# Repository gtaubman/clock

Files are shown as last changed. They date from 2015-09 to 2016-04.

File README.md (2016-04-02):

# Digital LED Clock

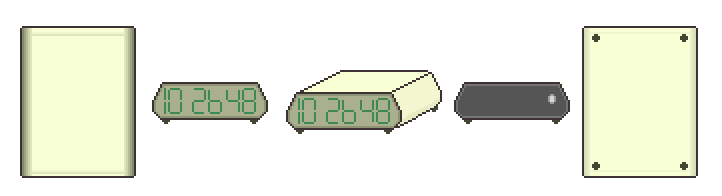
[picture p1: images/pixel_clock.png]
Pixel Clock


This project contains KiCad board schematics, PCB layouts, and firmware for my
digital clock.

The clock features buttons to set the time, a hold button to aid in syncing the
clock to another time source, and a switch to toggle the right-most display
between showing seconds and the current temperature as reported by the real-time
clock.

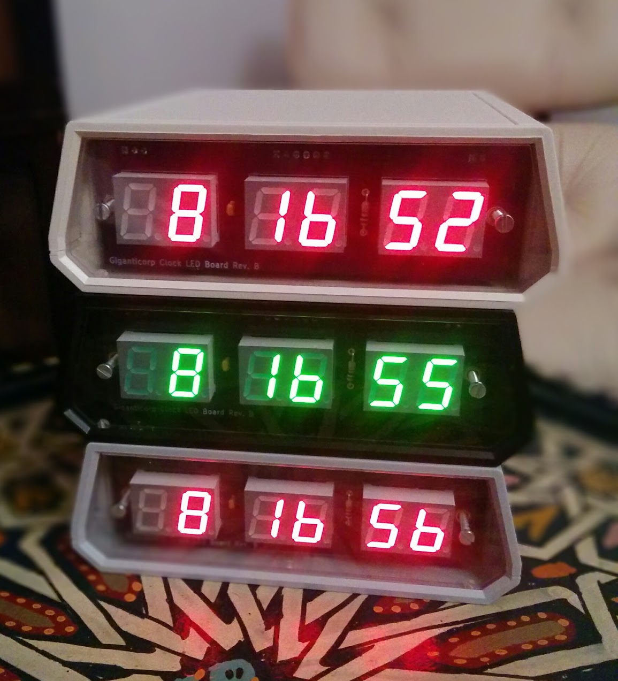
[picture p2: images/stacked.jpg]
Clock In Case

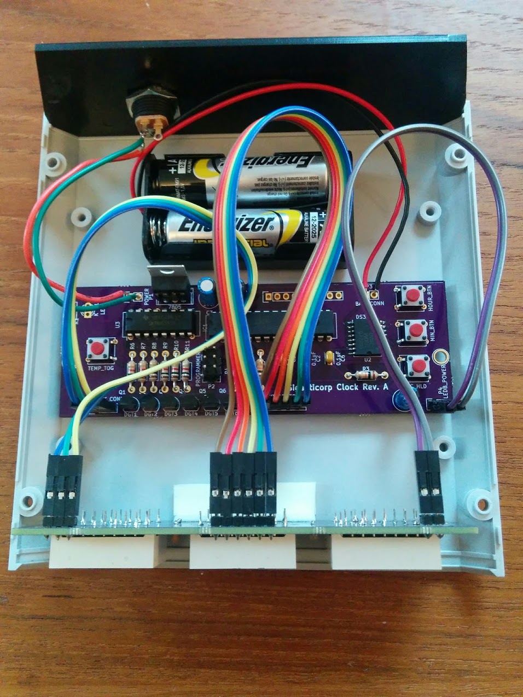
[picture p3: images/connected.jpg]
Clock Inside


The clock is divided into two PCBs:

## The LED Board

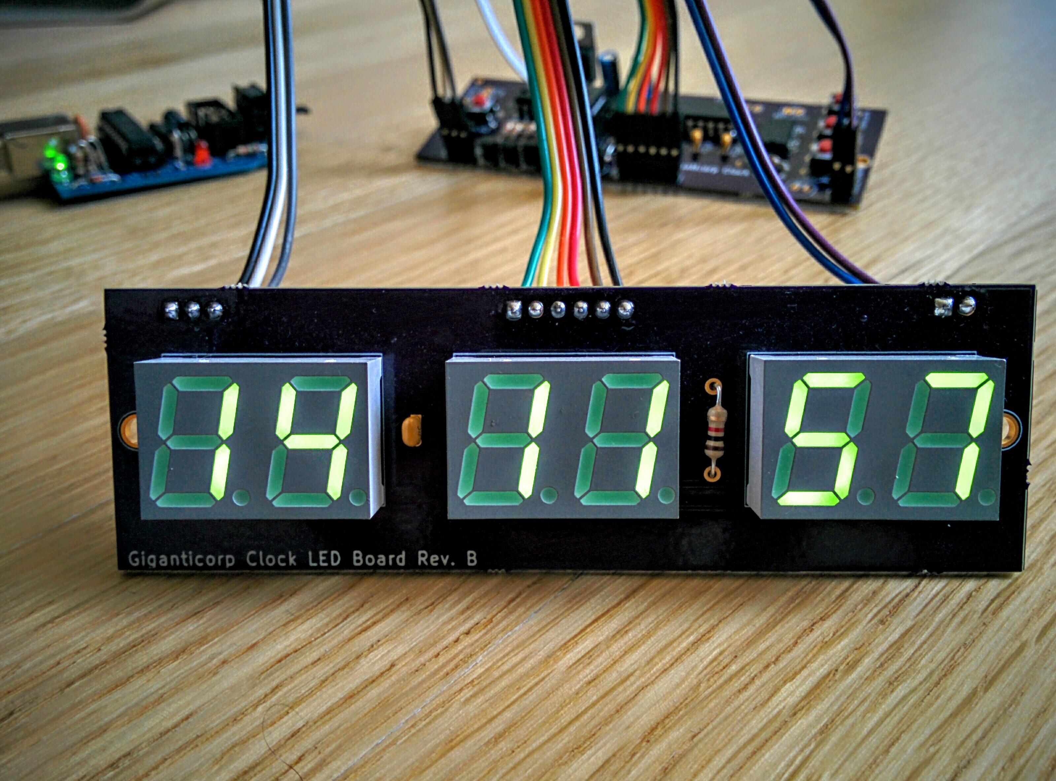
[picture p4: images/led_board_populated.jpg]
LED Board Populated


Schematic:

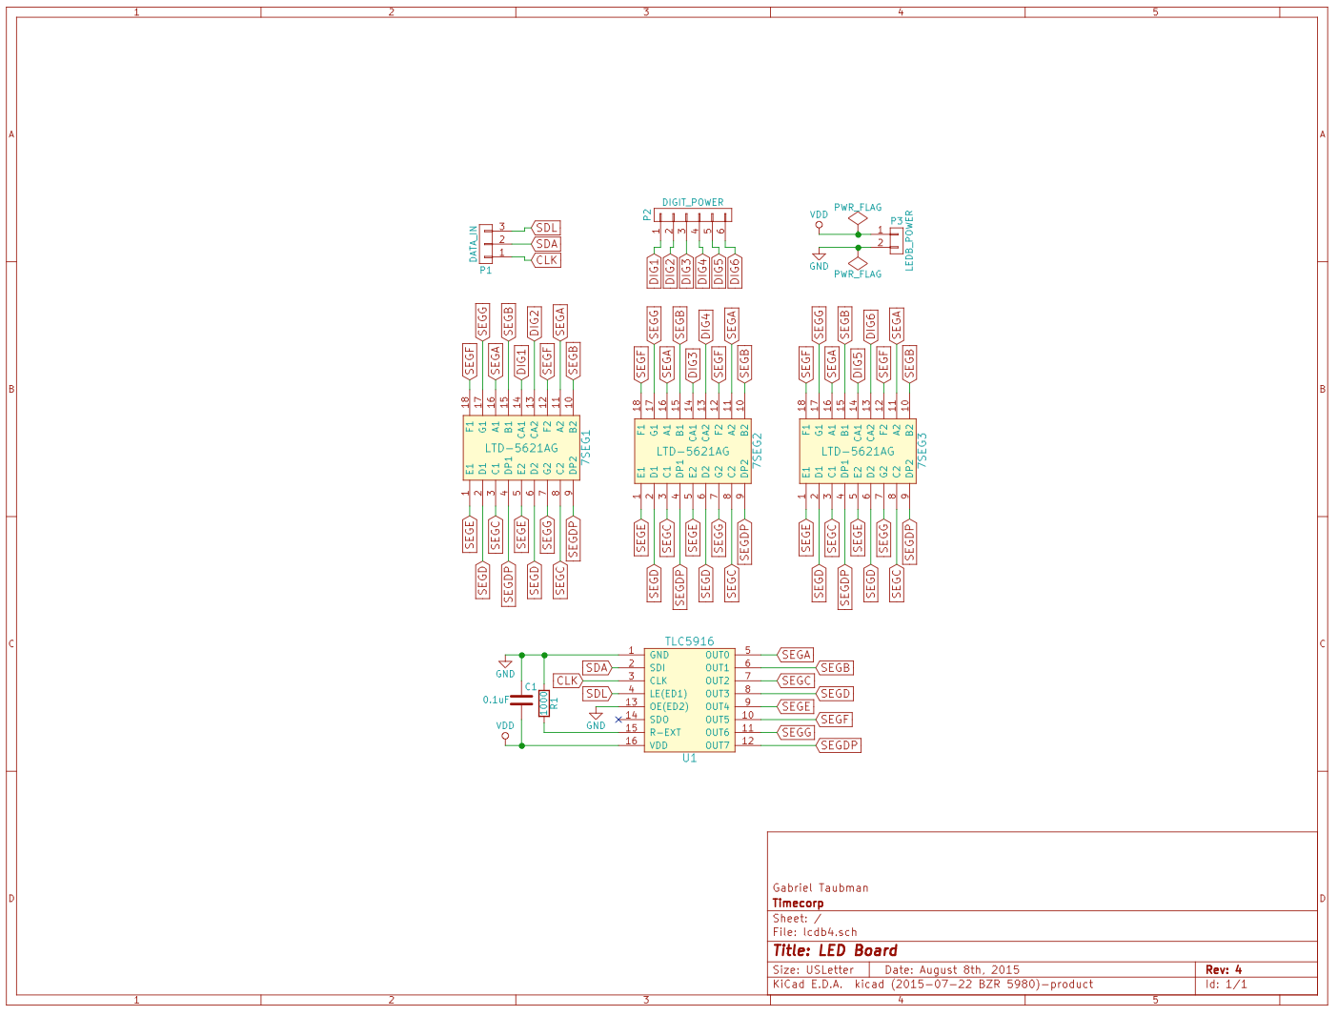
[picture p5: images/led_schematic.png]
LED Board Schematic


PCB Layout:

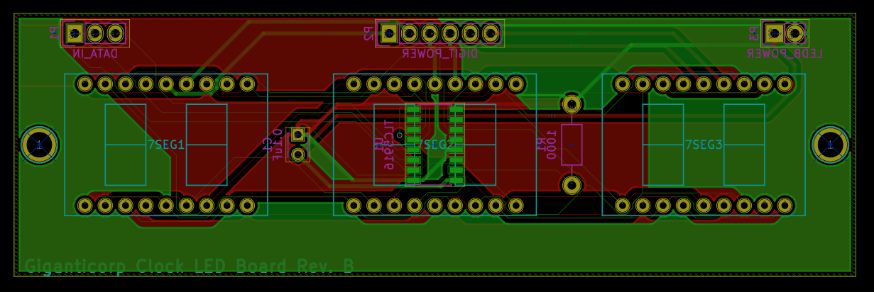
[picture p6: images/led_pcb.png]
LED Board PCB


PCB fabricated by OSH Park:

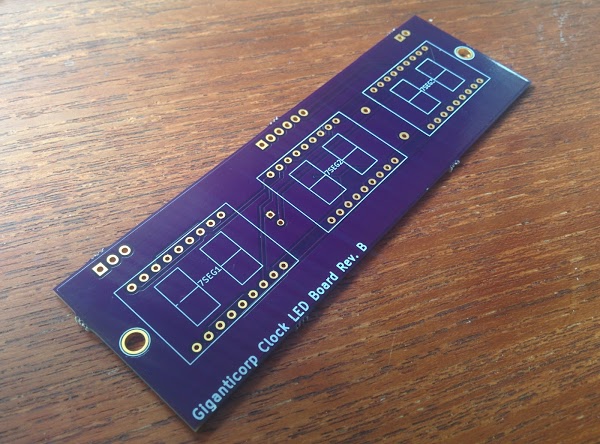
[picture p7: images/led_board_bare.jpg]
LED Board


This board contains:

1.  Three 2-digit 7-segment displays (Lite-On LTG-5612AG).
1.  A TLC5916 constant-current LED driver to drive the LEDs.
1.  A 0.1 uF decoupling capacitor for the TLC5916.
1.  A 1000 Ohm resistor to set the current allowed through the TLC5916.
1.  6 power pins to drive the individual digits.
1.  3 serial data pins to drive the TLC5916 (serial data, serial clock, latch).
1.  2 pins for power and ground for the TLC5916.

## The Clock Board

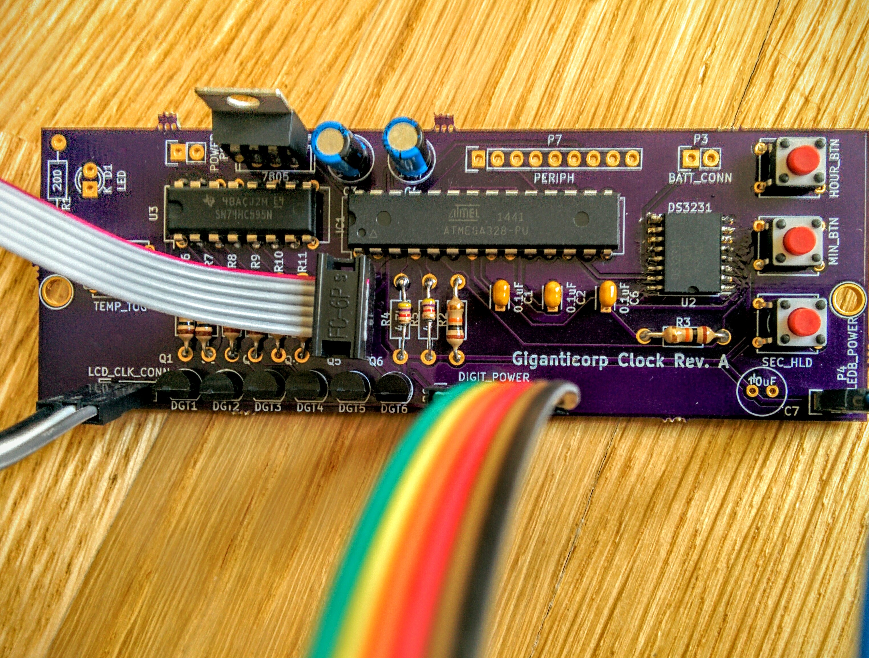
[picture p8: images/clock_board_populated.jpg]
Clock Board Populated


Schematic:

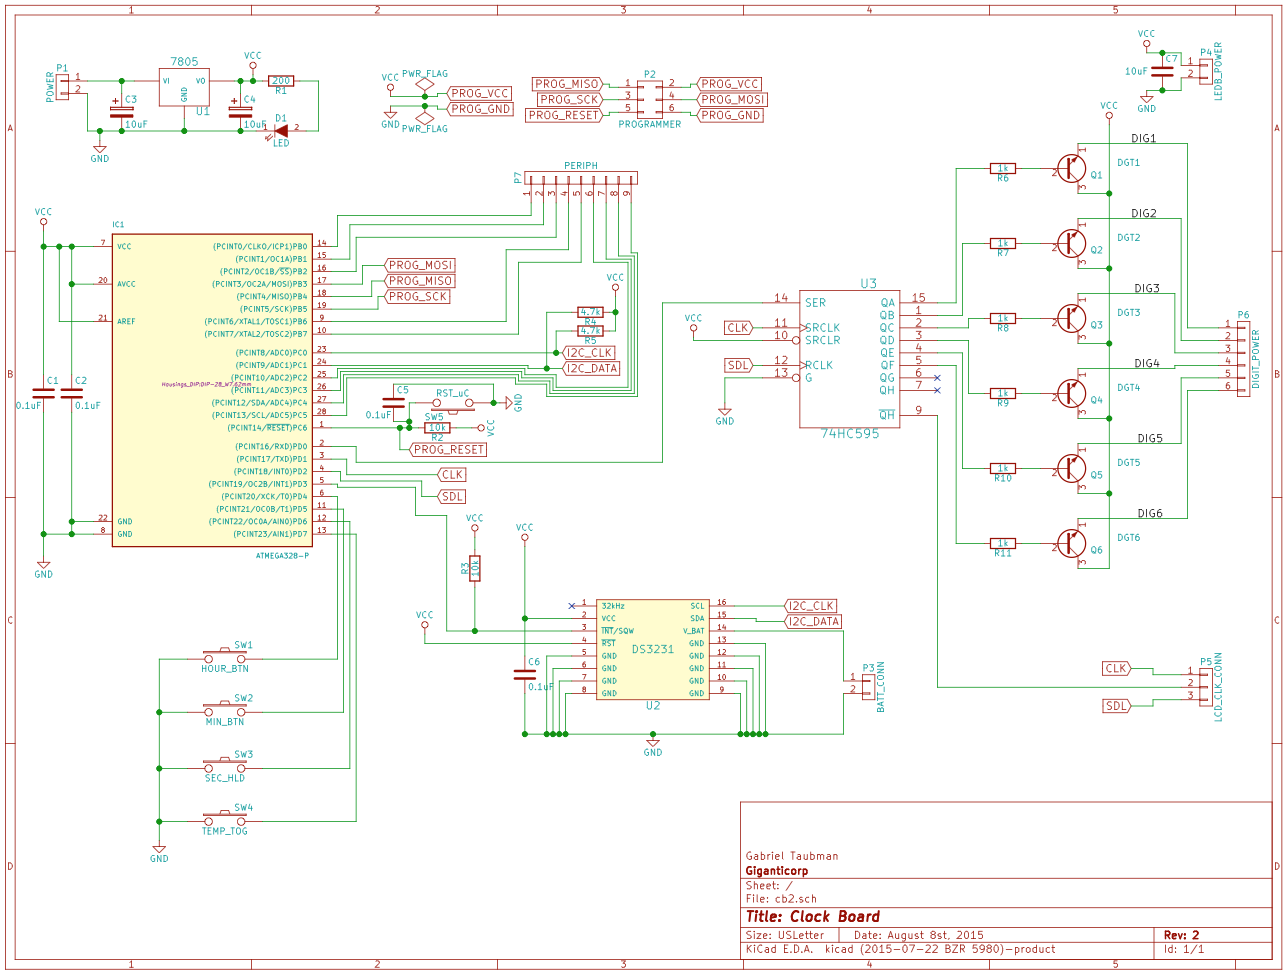
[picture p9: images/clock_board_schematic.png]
Clock Board Schematic


PCB Layout:

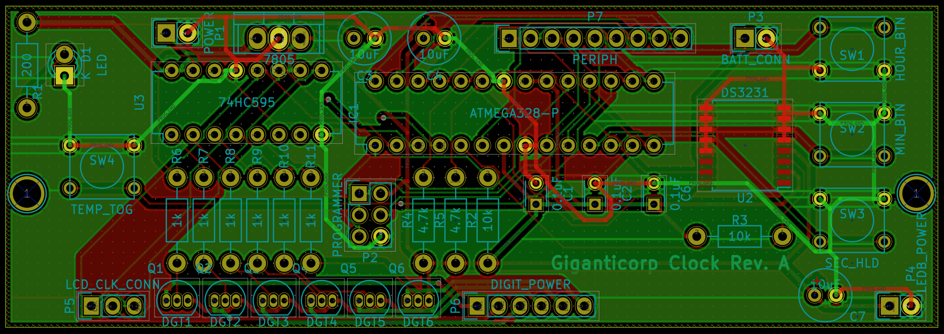
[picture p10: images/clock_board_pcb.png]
Clock Board PCB


PCB fabricated by OSH Park:

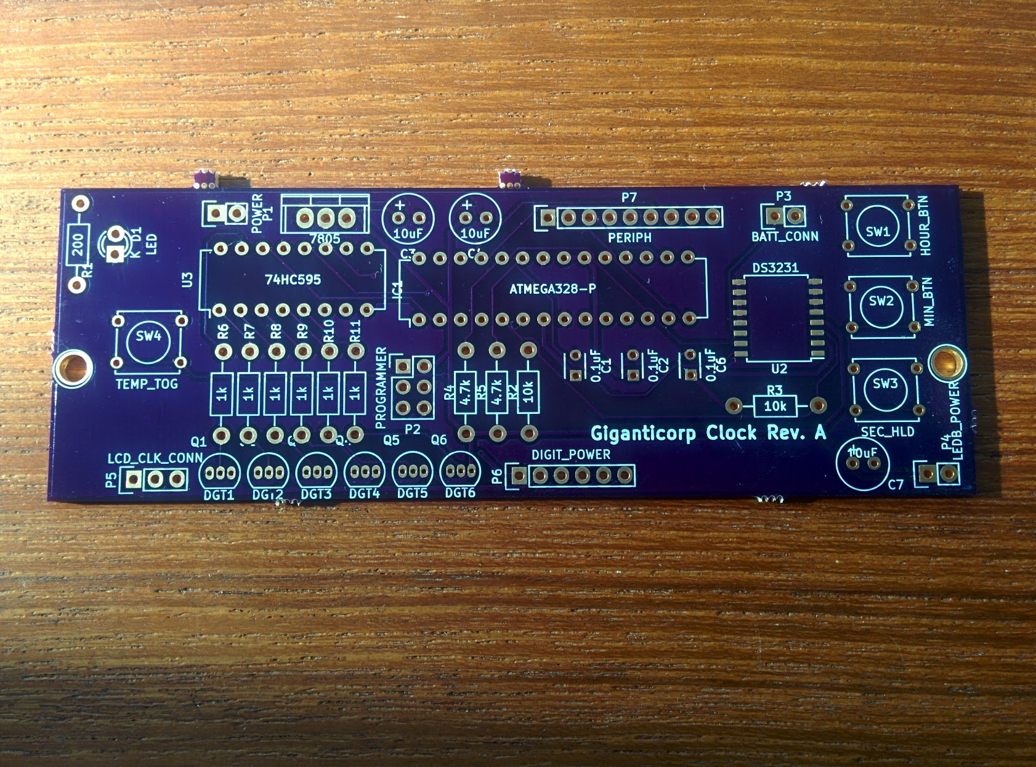
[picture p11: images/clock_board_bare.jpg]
Clock Board


The clock board is responsible for driving the entire clock logic, as well as
interfacing with the real-time clock chip, and allowing user control over the
clock functionality.  It consists of:

1.  One Atmega 328pu running the show.
1.  One DS3231 real-time clock, communicating with the AVR over i2c.
1.  One 74HC595 shift register to control which digit is powered on.
1.  6 transistors to power on digits.
1.  6 1k, 2 4.7k, and 2 10k resistors.
1.  4 push buttons for setting the time and temperature display modes.
1.  3 decoupling capacitors.
1.  2 10uF capacitors and a 7805 voltage regulator for supplying power.
1.  Pins to send power, data, and chip power to the LED board.
1.  An optional LED to indicate when the board is powered on.

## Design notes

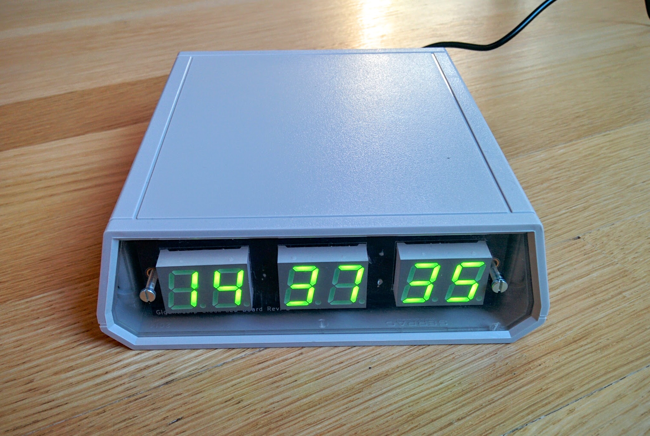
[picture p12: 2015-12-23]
images/clock_case.jpg

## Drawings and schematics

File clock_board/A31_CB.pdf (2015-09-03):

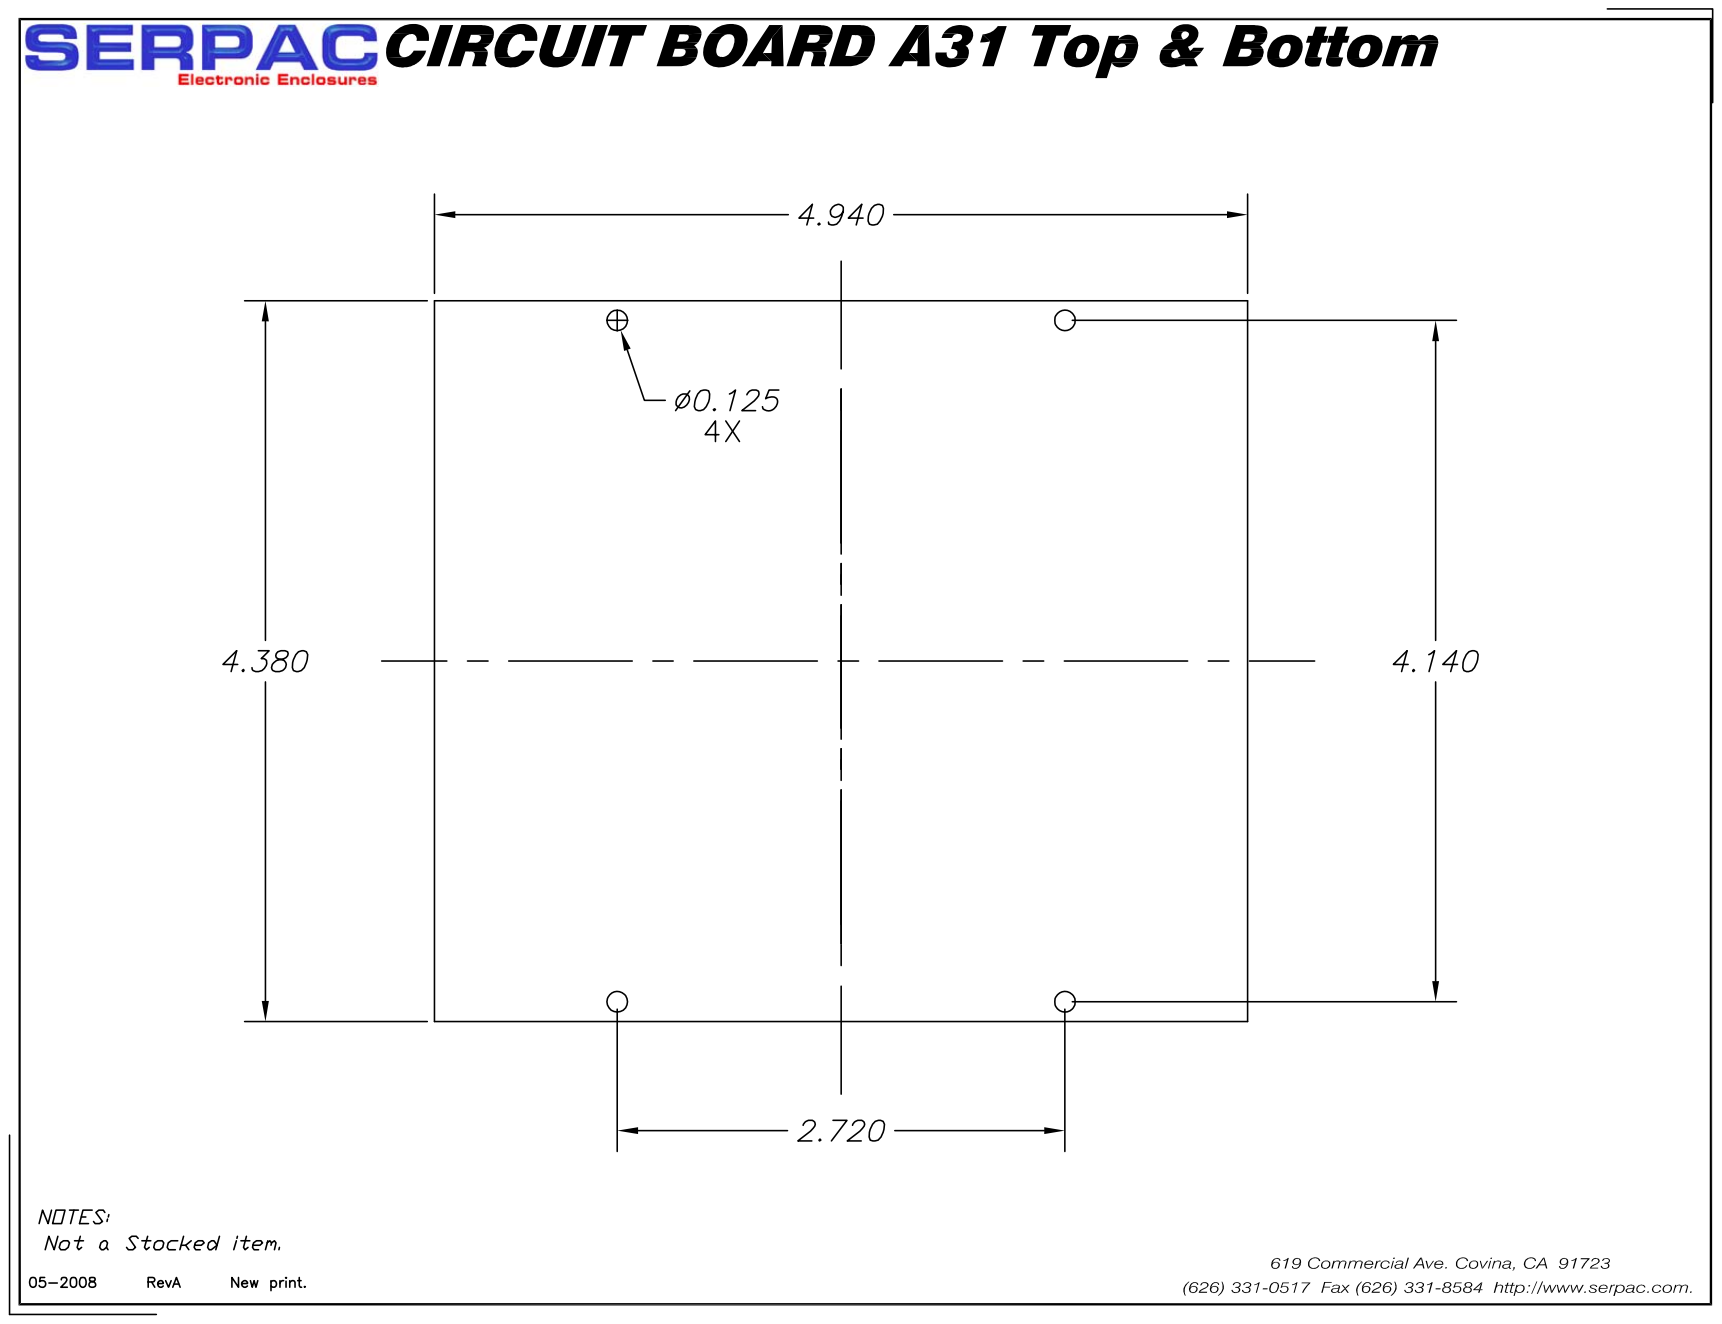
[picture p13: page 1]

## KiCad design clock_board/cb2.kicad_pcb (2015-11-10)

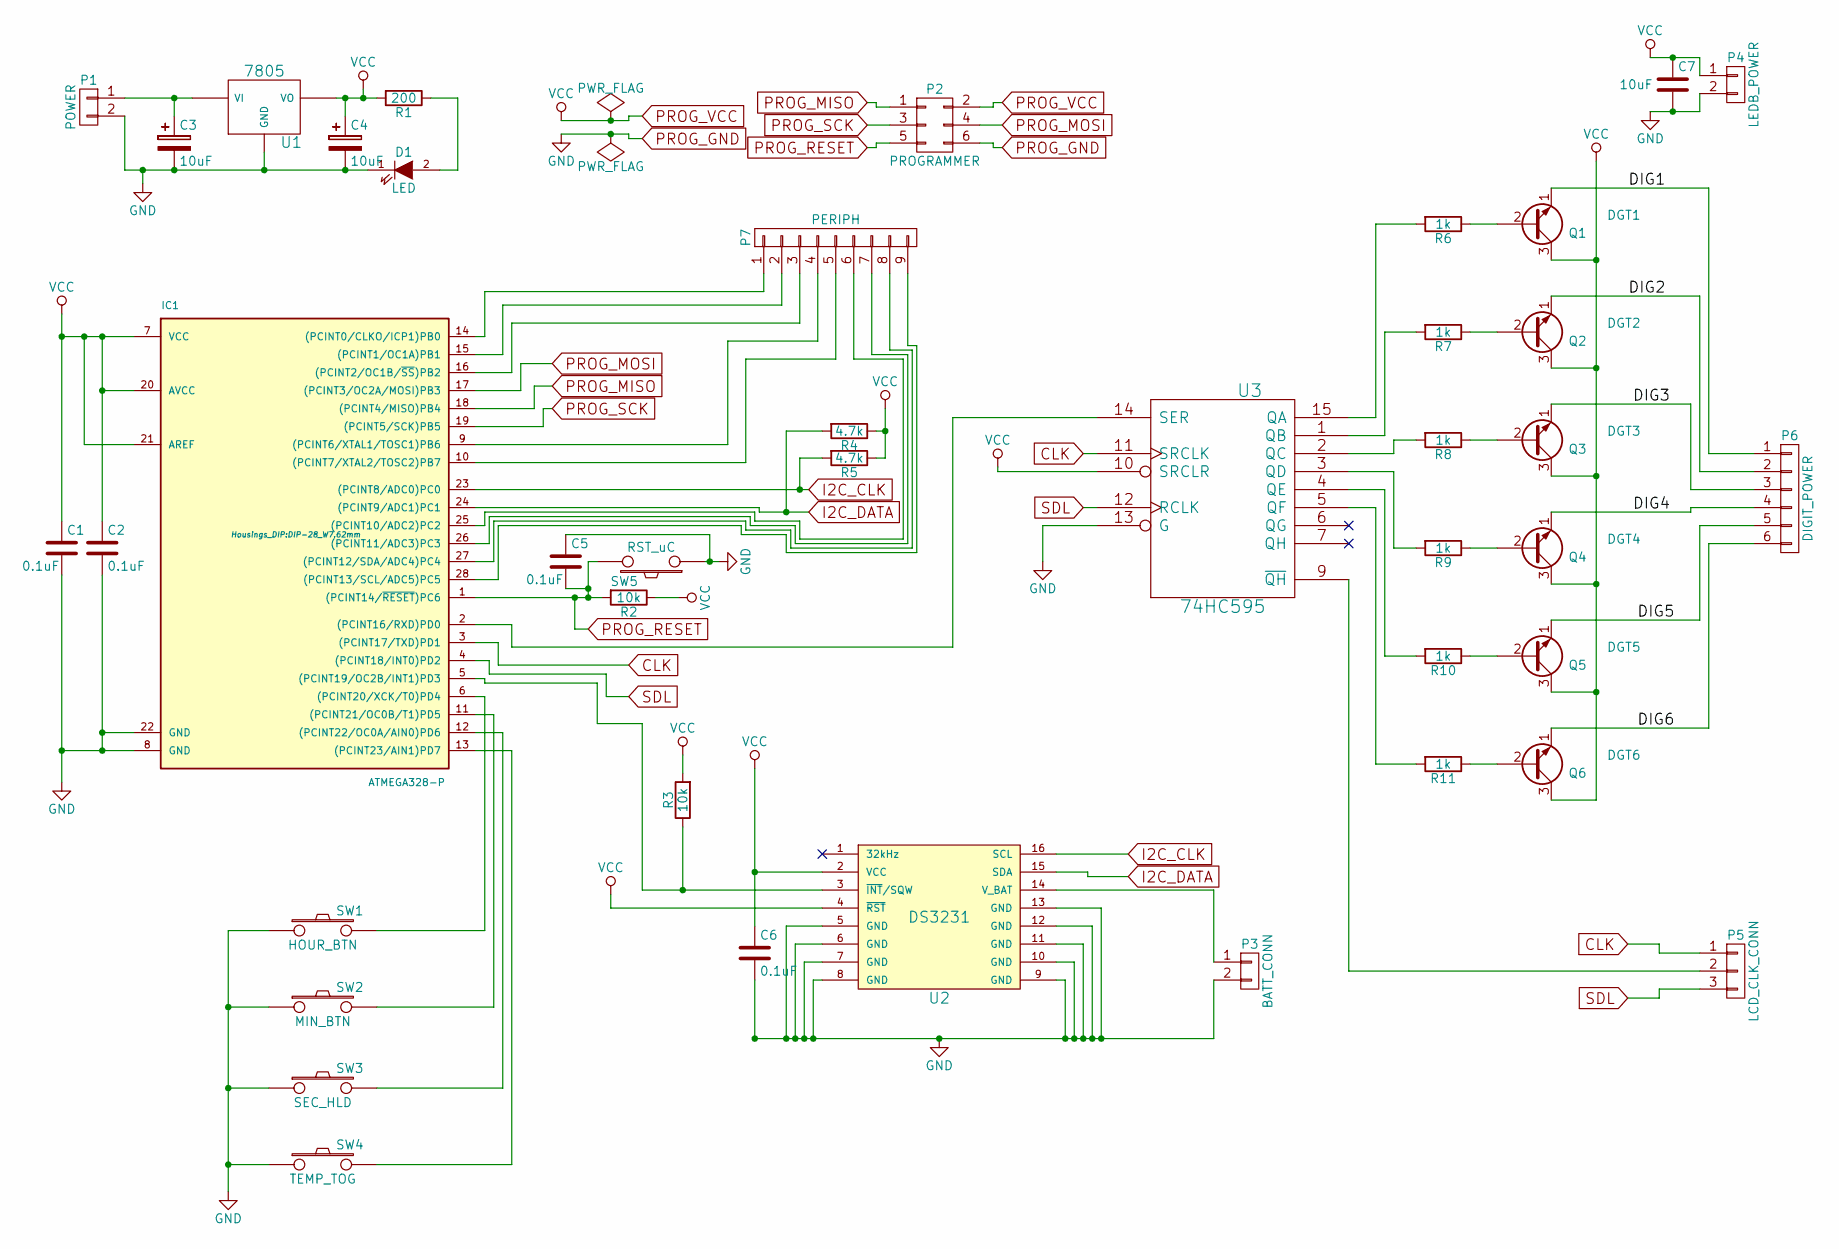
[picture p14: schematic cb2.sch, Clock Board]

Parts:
C1, C2, C5, C6: 0.1uF; C_Disc_D3_P2.5
C3, C4, C7: 10uF; Elko_vert_11.2x6.3mm_RM2.5
D1: LED; LED-3MM
IC1: ATMEGA328-P; DIP-28_W7.62mm
P1: POWER; Pin_Header_Straight_1x02
P2: PROGRAMMER; Pin_Header_Straight_2x03
P3: BATT_CONN; Pin_Header_Straight_1x02
P4: LEDB_POWER; Pin_Header_Straight_1x02
P5: LCD_CLK_CONN; Pin_Header_Straight_1x03
P6: DIGIT_POWER; Pin_Header_Straight_1x06
P7: PERIPH; Pin_Header_Straight_1x09
Q1: DGT1; TO-92_Inline_Narrow_Oval
Q2: DGT2; TO-92_Inline_Narrow_Oval
Q3: DGT3; TO-92_Inline_Narrow_Oval
Q4: DGT4; TO-92_Inline_Narrow_Oval
Q5: DGT5; TO-92_Inline_Narrow_Oval
Q6: DGT6; TO-92_Inline_Narrow_Oval
R1: 200; Resistor_Horizontal_RM10mm
R2, R3: 10k; Resistor_Horizontal_RM10mm
R4, R5: 4.7k; Resistor_Horizontal_RM10mm
R6, R7, R8, R9, R10, R11: 1k; Resistor_Horizontal_RM10mm
SW1: HOUR_BTN; SW_PUSH_SMALL
SW2: MIN_BTN; SW_PUSH_SMALL
SW3: SEC_HLD; SW_PUSH_SMALL
SW4: TEMP_TOG; SW_PUSH_SMALL
SW5: RST_uC; SW_PUSH_SMALL
U1: 7805; TO-220
U2: DS3231; SOIC-16_7.5x10.3mm_Pitch1.27mm
U3: 74HC595; DIP-16_W7.62mm

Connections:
/DIG1: P6.1, Q1.1 (E)
/DIG2: P6.2, Q2.1 (E)
/DIG3: P6.3, Q3.1 (E)
/DIG4: P6.4, Q4.1 (E)
/DIG5: P6.5, Q5.1 (E)
/DIG6: P6.6, Q6.1 (E)
CLK: IC1.3 ((PCINT17/TXD)PD1), P5.1, U3.11 (SRCLK)
I2C_CLK: IC1.23 ((PCINT8/ADC0)PC0), R5.2, U2.16 (SCL)
I2C_DATA: IC1.24 ((PCINT9/ADC1)PC1), R4.2, U2.15 (SDA)
unnamed: C3.1, P1.1, U1.1 (VI)
unnamed: D1.2 (A), R1.1
unnamed: IC1.2 ((PCINT16/RXD)PD0), U3.14 (SER)
unnamed: IC1.5 ((PCINT19/OC2B/INT1)PD3), R3.1, U2.3 (~INT~/SQW)
unnamed: IC1.6 ((PCINT20/XCK/T0)PD4), SW1.2
unnamed: IC1.9 ((PCINT6/XTAL1/TOSC1)PB6), P7.4
unnamed: IC1.10 ((PCINT7/XTAL2/TOSC2)PB7), P7.5
unnamed: IC1.11 ((PCINT21/OC0B/T1)PD5), SW2.2
unnamed: IC1.12 ((PCINT22/OC0A/AIN0)PD6), SW3.2
unnamed: IC1.13 ((PCINT23/AIN1)PD7), SW4.2
unnamed: IC1.14 ((PCINT0/CLKO/ICP1)PB0), P7.1
unnamed: IC1.15 ((PCINT1/OC1A)PB1), P7.2
unnamed: IC1.16 ((PCINT2/OC1B/~SS~)PB2), P7.3
unnamed: IC1.25 ((PCINT10/ADC2)PC2), P7.6
unnamed: IC1.26 ((PCINT11/ADC3)PC3), P7.7
unnamed: IC1.27 ((PCINT12/SDA/ADC4)PC4), P7.8
unnamed: IC1.28 ((PCINT13/SCL/ADC5)PC5), P7.9
unnamed: P3.1, U2.14 (V_BAT)
unnamed: P5.2, U3.9 (~QH)
unnamed: Q1.2 (B), R6.1
unnamed: Q2.2 (B), R7.1
unnamed: Q3.2 (B), R8.1
unnamed: Q4.2 (B), R9.1
unnamed: Q5.2 (B), R10.1
unnamed: Q6.2 (B), R11.1
unnamed: R6.2, U3.15 (QA)
unnamed: R7.2, U3.1 (QB)
unnamed: R8.2, U3.2 (QC)
unnamed: R9.2, U3.3 (QD)
unnamed: R10.2, U3.4 (QE)
unnamed: R11.2, U3.5 (QF)
PROG_GND: C1.2, C2.2, C3.2, C4.2, C5.1, C6.2, C7.2, D1.1 (K), IC1.8 (GND), IC1.22 (GND), P1.2, P2.6, P3.2, P4.2, SW1.1, SW2.1, SW3.1, SW4.1, SW5.1, U1.2 (GND), U2.5 (GND), U2.6 (GND), U2.7 (GND), U2.8 (GND), U2.9 (GND), U2.10 (GND), U2.11 (GND), U2.12 (GND), U2.13 (GND), U3.8 (GND), U3.13 (G)
PROG_MISO: IC1.18 ((PCINT4/MISO)PB4), P2.1
PROG_MOSI: IC1.17 ((PCINT3/OC2A/MOSI)PB3), P2.4
PROG_RESET: C5.2, IC1.1 ((PCINT14/~RESET~)PC6), P2.5, R2.2, SW5.2
PROG_SCK: IC1.19 ((PCINT5/SCK)PB5), P2.3
PROG_VCC: C1.1, C2.1, C4.1, C6.1, C7.1, IC1.7 (VCC), IC1.20 (AVCC), IC1.21 (AREF), P2.2, P4.1, Q1.3 (C), Q2.3 (C), Q3.3 (C), Q4.3 (C), Q5.3 (C), Q6.3 (C), R1.2, R2.1, R3.2, R4.1, R5.1, U1.3 (VO), U2.2 (VCC), U2.4 (~RST), U3.10 (SRCLR), U3.16 (VCC)
SDL: IC1.4 ((PCINT18/INT0)PD2), P5.3, U3.12 (RCLK)

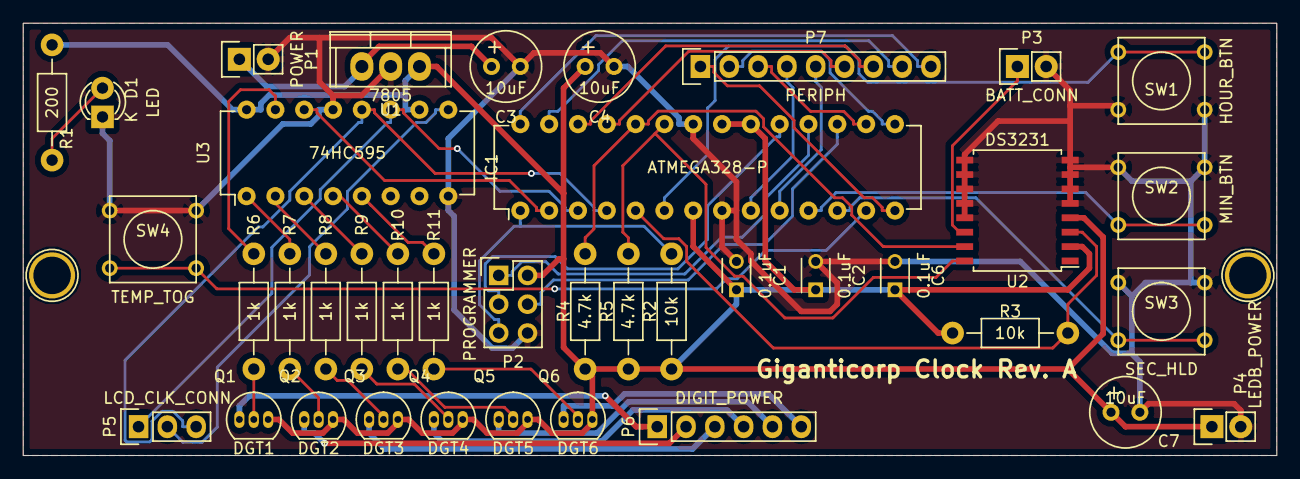
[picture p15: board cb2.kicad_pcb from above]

Board: 2 copper layers, 110.5 x 38.1 mm, 41 parts (0 on the bottom side), 47 nets.

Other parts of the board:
REF1, REF2: 1pin

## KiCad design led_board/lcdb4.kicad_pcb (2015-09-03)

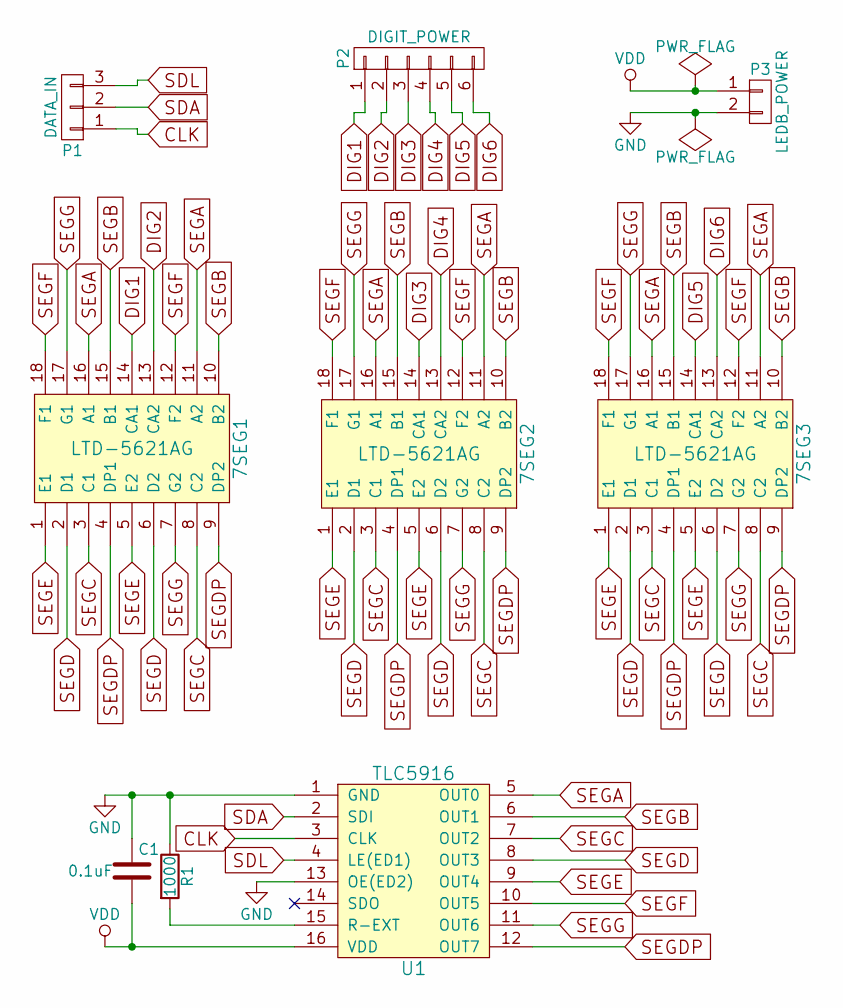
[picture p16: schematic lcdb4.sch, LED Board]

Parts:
7SEG1, 7SEG2, 7SEG3: LTD-5621AG
C1: 0.1uF; C_Disc_D3_P2.5
P1: DATA_IN; Pin_Header_Straight_1x03
P2: DIGIT_POWER; Pin_Header_Straight_1x06
P3: LEDB_POWER; Pin_Header_Straight_1x02
R1: 1000; Resistor_Horizontal_RM10mm
U1: TLC5916; SOIC-16_3.9x9.9mm_Pitch1.27mm

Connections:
CLK: P1.1, U1.3 (CLK)
DIG1: 7SEG1.14 (CA1), P2.1
DIG2: 7SEG1.13 (CA2), P2.2
DIG3: 7SEG2.14 (CA1), P2.3
DIG4: 7SEG2.13 (CA2), P2.4
DIG5: 7SEG3.14 (CA1), P2.5
DIG6: 7SEG3.13 (CA2), P2.6
GND: C1.1, P3.2, R1.1, U1.1 (GND), U1.13 (OE(ED2))
unnamed: R1.2, U1.15 (R-EXT)
SDA: P1.2, U1.2 (SDI)
SDL: P1.3, U1.4 (LE(ED1))
SEGA: 7SEG1.11 (A2), 7SEG1.16 (A1), 7SEG2.11 (A2), 7SEG2.16 (A1), 7SEG3.11 (A2), 7SEG3.16 (A1), U1.5 (OUT0)
SEGB: 7SEG1.10 (B2), 7SEG1.15 (B1), 7SEG2.10 (B2), 7SEG2.15 (B1), 7SEG3.10 (B2), 7SEG3.15 (B1), U1.6 (OUT1)
SEGC: 7SEG1.3 (C1), 7SEG1.8 (C2), 7SEG2.3 (C1), 7SEG2.8 (C2), 7SEG3.3 (C1), 7SEG3.8 (C2), U1.7 (OUT2)
SEGD: 7SEG1.2 (D1), 7SEG1.6 (D2), 7SEG2.2 (D1), 7SEG2.6 (D2), 7SEG3.2 (D1), 7SEG3.6 (D2), U1.8 (OUT3)
SEGDP: 7SEG1.4 (DP1), 7SEG1.9 (DP2), 7SEG2.4 (DP1), 7SEG2.9 (DP2), 7SEG3.4 (DP1), 7SEG3.9 (DP2), U1.12 (OUT7)
SEGE: 7SEG1.1 (E1), 7SEG1.5 (E2), 7SEG2.1 (E1), 7SEG2.5 (E2), 7SEG3.1 (E1), 7SEG3.5 (E2), U1.9 (OUT4)
SEGF: 7SEG1.12 (F2), 7SEG1.18 (F1), 7SEG2.12 (F2), 7SEG2.18 (F1), 7SEG3.12 (F2), 7SEG3.18 (F1), U1.10 (OUT5)
SEGG: 7SEG1.7 (G2), 7SEG1.17 (G1), 7SEG2.7 (G2), 7SEG2.17 (G1), 7SEG3.7 (G2), 7SEG3.17 (G1), U1.11 (OUT6)
VDD: C1.2, P3.1, U1.16 (VDD)

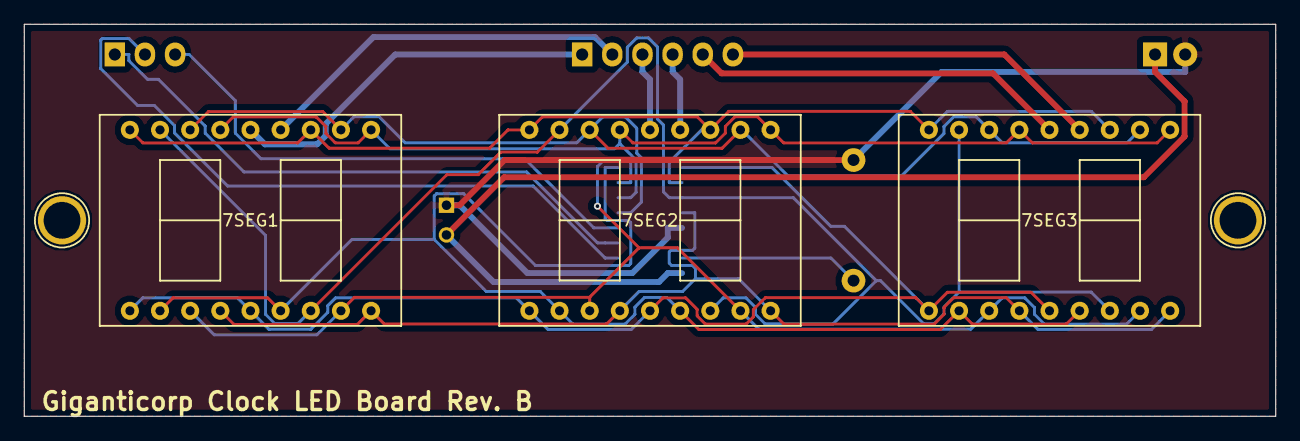
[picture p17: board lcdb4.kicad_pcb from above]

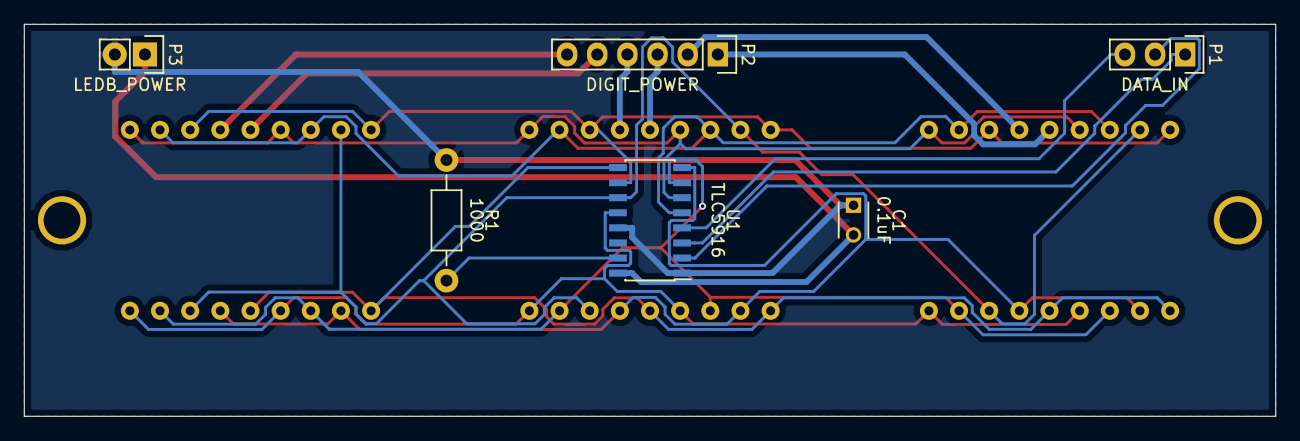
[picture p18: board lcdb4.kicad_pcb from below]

Board: 2 copper layers, 105.4 x 33.0 mm, 11 parts (6 on the bottom side), 20 nets.

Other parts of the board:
REF1, REF2: 1pin

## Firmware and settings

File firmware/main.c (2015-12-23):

/* Name: main.c
 * Author: <insert your name here>
 * Copyright: <insert your copyright message here>
 * License: <insert your license reference here>
 */

#include <avr/io.h>
#include <avr/interrupt.h>
#include <util/delay.h>
#include <util/twi.h>

#include "button.h"
#include "i2cmaster.h"
#include "rtc.h"

// Ports for serial clock, data, and latch.
#define SDA_PORT PORTD
#define CLK_PORT PORTD
#define SDL_PORT PORTD

// Pins for serial clock, data, and latch.
#define SDA_PIN 0
#define CLK_PIN 1
#define SDL_PIN 2

#define RTC_INTERRUPT_PIN 3

#define HOUR_BTN_PIN 4
#define MIN_BTN_PIN 5
#define SEC_BTN_PIN 6
#define TEMP_TOG_BTN_PIN 7

typedef struct digit {
  unsigned int a : 1;
  unsigned int b : 1;
  unsigned int c : 1;
  unsigned int d : 1;
  unsigned int e : 1;
  unsigned int f : 1;
  unsigned int g : 1;
  unsigned int dp : 1;
} Digit;

// Digit segment configuration for each digit.
Digit zero =  {1, 1, 1, 1, 1, 1, 0, 0};
Digit one =   {0, 1, 1, 0, 0, 0, 0, 0};
Digit two =   {1, 1, 0, 1, 1, 0, 1, 0};
Digit three = {1, 1, 1, 1, 0, 0, 1, 0};
Digit four =  {0, 1, 1, 0, 0, 1, 1, 0};
Digit five =  {1, 0, 1, 1, 0, 1, 1, 0};
Digit six =   {0, 0, 1, 1, 1, 1, 1, 0};
Digit seven = {1, 1, 1, 0, 0, 0, 0, 0};
Digit eight = {1, 1, 1, 1, 1, 1, 1, 0};
Digit nine =  {1, 1, 1, 0, 0, 1, 1, 0};
Digit clear = {0, 0, 0, 0, 0, 0, 0, 0};

// A lookup table from actual integer to 7-segment display integer.
Digit* digits[11] = {
  &zero,
  &one,
  &two,
  &three,
  &four,
  &five,
  &six,
  &seven,
  &eight,
  &nine,
  &clear,
};

volatile uint8_t update_time = 0;

volatile int time[6] = {0, 0, 0, 0, 0, 0};

Button hour_button;
Button min_button;
Button sec_button;
Button temp_toggle_button;
uint8_t holding;
uint8_t show_temp;

#define CLOCK_LOW() (CLK_PORT &= ~(1 << CLK_PIN))
#define CLOCK_HIGH() (CLK_PORT |= 1 << CLK_PIN)

#define DATA_LOW() (SDA_PORT &= ~(1 << SDA_PIN))
#define DATA_HIGH() (SDA_PORT |= 1 << SDA_PIN)

#define LATCH_LOW() (SDL_PORT &= ~(1 << SDL_PIN))
#define LATCH_HIGH() (SDL_PORT |= 1 << SDL_PIN)

void set_digit(int digit_number, int digit_value) {
  // Set the clock low to start with.
  CLOCK_LOW();

  // Also make sure we're not latched.
  LATCH_LOW();

  // Shift out the digit value data first.
  for (int i = 7; i >= 0; --i) {
    // Reinterpret our digit struct as an int to pull out each segment's bit.
    (*((uint8_t*) digits[digit_value]) & (1 << i)) ? DATA_HIGH() : DATA_LOW();
    CLOCK_HIGH();
    CLOCK_LOW();
  }

  // Shift out the digit selector.
  for (int i = 7; i >= 0; --i) {
    digit_value < 0 ? DATA_LOW() : (i == digit_number) ? DATA_HIGH() : DATA_LOW();
    CLOCK_HIGH();
    CLOCK_LOW();
  }

  LATCH_HIGH();
  LATCH_LOW();
}

inline void set_time() {
  uint8_t sec = 0;
  if (!holding) {
    if (rtc_read_seconds(&sec) != 0) {
      time[4] = time[5] = 9;
    } else {
      time[4] = sec / 10;
      time[5] = sec % 10;
    }
  }
  if (rtc_read_minutes(&sec) != 0) {
    time[2] = time[3] = 9;
  } else {
    time[2] = sec / 10;
    time[3] = sec % 10;
  }
  if (rtc_read_hours(&sec) != 0) {
    time[0] = time[1] = 9;
  } else {
    time[0] = sec / 10;
    time[1] = sec % 10;

    // If the hours tens place is zero, don't show it at all.  We don't want
    // it to be 08:00:00, just 8:00:00.  However, if both hour digits are
    // zero, then we want to show them both.
    if (time[0] == 0 && time[1] != 0) {
      time[0] = -1;
    }
  }

  if (show_temp) {
    if (rtc_read_temp_c(&sec) != 0) {
      time[4] = time[5] = 9;
    } else {
      sec = 32 + (sec * 9.0 / 5.0);
      time[4] = sec / 10;
      time[5] = sec % 10;
    }
  }
}

void process_button_input() {
  ingest_button_value(&hour_button, (PIND & (1 << HOUR_BTN_PIN)) == 0);
  if (is_button_pushed(&hour_button)) {
    // They hit the hours button.
    rtc_inc_hours();
    set_time();
  }

  ingest_button_value(&min_button, (PIND & (1 << MIN_BTN_PIN)) == 0);
  if (is_button_pushed(&min_button)) {
    // They hit the mins button.
    rtc_inc_mins();
    set_time();
  }

  ingest_button_value(&sec_button, (PIND & (1 << SEC_BTN_PIN)) == 0);
  if (is_button_pushed(&sec_button)) {
    if (holding) {
      // If we were holding, grab the held seconds and set them again.    
      rtc_set_secs(10 * time[4] + time[5]);
    }
    holding = !holding;
  }

  ingest_button_value(&temp_toggle_button,
                      (PIND & (1 << TEMP_TOG_BTN_PIN)) == 0);
  if (is_button_pushed(&temp_toggle_button)) {
    show_temp = !show_temp;
    set_time();
  }
}

int main(void) {
  // Make the serial control ports all output pins.
  DDRD |= 1 << SDA_PIN;
  DDRD |= 1 << CLK_PIN;
  DDRD |= 1 << SDL_PIN;

  // Set up the hour, minute, and seconds button pins as inputs with the pullup
  // enabled.
  DDRD &= ~(1 << HOUR_BTN_PIN);
  PORTD |= (1 << HOUR_BTN_PIN);

  DDRD &= ~(1 << MIN_BTN_PIN);
  PORTD |= (1 << MIN_BTN_PIN);

  DDRD &= ~(1 << SEC_BTN_PIN);
  PORTD |= (1 << SEC_BTN_PIN);

  DDRD &= ~(1 << TEMP_TOG_BTN_PIN);
  PORTD |= (1 << TEMP_TOG_BTN_PIN);

  // Enable interrupts for both rising and falling edges on the RTC interrupt
  // pin.
  // First we mark the pin as an input pin.
  DDRD &= ~(1 << RTC_INTERRUPT_PIN);

  // Next we enable the internal pullup.
  PORTD |= (1 << RTC_INTERRUPT_PIN);

  // The DS3231 has a falling edge of its 1 Hz square wave lined up with second
  // changes, so we only trigger on falling edges.
  EICRA |= (1 << ISC11);

  // Finally, enable INT1.
  EIMSK |= (1 << INT1);

  // Initialize our i2c interface to talk to the DS3231.
  i2c_init();

  holding = 0;
  show_temp = 0;

  sei();

#ifdef SET_TIME
  rtc_set_time(10, 17, 5);
#endif

  if (rtc_enable_square_wave() != 0) {
    return -1;
  }

  if (rtc_set_24hour(0) != 0) {
    return -1;
  }

  uint8_t button_counter = 0;
  while (1) {
    if (update_time) {
      update_time = 0;

      // Because set_time() takes time to fetch the time from the DS3231, the
      // last digit in the cycle would be left on for extra time (the normal
      // amount of time plus however long it takes to fetch the time from the
      // DS3231).  This would result it pulsing brighter.  To keep it the same
      // brightness regardless of whether or not we fetch the time, we disable
      // it before fetching the time.
      set_digit(5, 10);

      set_time();
    }

    if (++button_counter == 8) {
      // Handle any buttons the user is pushing.
      // In order to keep the digits on for the same amount of time, we only
      // check for button presses every 8th time through the loop.
      process_button_input();
      button_counter = 0;
    }

    // Loop through and display all the digits.
    for (int i = 0; i < 6; ++i) {
      set_digit(i, time[i]);
    }
  }

  return 0;
}

ISR(INT1_vect) {
  update_time = 1;
}

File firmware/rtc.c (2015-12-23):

#include "rtc.h"
#include "i2cmaster.h"

#define RTC_ADDRESS 0xD0


#define SECONDS_ADDRESS 0x00
#define MINUTES_ADDRESS 0x01
#define HOURS_ADDRESS 0x02
#define DAY_ADDRESS 0x03
#define DATE_ADDRESS 0x04

#define CONTROL_ADDRESS 0x0E

uint8_t dec2bcd(uint8_t d) {
    return ((d/10 * 16) + (d % 10));
}

uint8_t bcd2dec(uint8_t b) {
    return ((b/16 * 10) + (b % 16));
}

uint8_t rtc_read_reg(uint8_t reg, uint8_t* val) {
  // Start off with a write.
  if (i2c_start(RTC_ADDRESS) != 0) {
    return 1;
  }

  // Indicate which register we'd like to read.
  if (i2c_write(reg) != 0) {
    return 2;
  }

  // Start again, indicating a read this time.
  if (i2c_rep_start(RTC_ADDRESS | 1) != 0) {
    return 3;
  }

  // Read one byte, and nack it because we're done.
  *val = i2c_readNak();

  // Done!
  i2c_stop();

  return 0;
}

uint8_t rtc_read_bcd_reg(uint8_t reg, uint8_t* val) {
  // Start off with a write.
  if (i2c_start(RTC_ADDRESS) != 0) {
    return 1;
  }

  // Indicate which register we'd like to read.
  if (i2c_write(reg) != 0) {
    return 2;
  }

  // Start again, indicating a read this time.
  if (i2c_rep_start(RTC_ADDRESS | 1) != 0) {
    return 3;
  }

  // Read one byte, and nack it because we're done.
  unsigned char r = i2c_readNak();
  *val = bcd2dec(r);

  // Done!
  i2c_stop();

  return 0;
}

uint8_t rtc_write_reg(uint8_t reg, uint8_t val) {
  // Start off!
  if (i2c_start(RTC_ADDRESS) != 0) {
    return 1;
  }

  if (i2c_write(reg) != 0) {
    return 2;
  }

  if (i2c_write(val) != 0) {
    return 3;
  }

  // Done!
  i2c_stop();

  return 0;
}

uint8_t rtc_read_seconds(uint8_t* seconds) {
  return rtc_read_bcd_reg(SECONDS_ADDRESS, seconds);
}

uint8_t rtc_read_minutes(uint8_t* minutes) {
  return rtc_read_bcd_reg(MINUTES_ADDRESS, minutes);
}

uint8_t rtc_read_hours(uint8_t* hours) {
  if (rtc_read_reg(HOURS_ADDRESS, hours) != 0) {
    return 1;
  }

  if (*hours & (1 << 6)) {
    // We're in 12 hour mode.  Remove the 5th bit which represents AM/PM and the
    // 6th bit which says we're in 12 hour mode.
    *hours &= ~(1 << 6);
    *hours &= ~(1 << 5);
  }
  *hours = bcd2dec(*hours);

  return 0;
}

uint8_t rtc_read_temp_c(uint8_t* temp_c) {
  return rtc_read_reg(0x11, temp_c);
}

uint8_t rtc_set_time(uint8_t h, uint8_t m, uint8_t s) {
  // Start off!
  if (i2c_start(RTC_ADDRESS) != 0) {
    return 1;
  }

  // Start off writing seconds, and then continue with minutes and hours.
  if (i2c_write(SECONDS_ADDRESS) != 0) {
    return 2;
  }

  if (i2c_write(dec2bcd(s)) != 0) {
    return 3;
  }
  if (i2c_write(dec2bcd(m)) != 0) {
    return 4;
  }
  if (i2c_write(dec2bcd(h)) != 0) {
    return 5;
  }

  // Done!
  i2c_stop();

  return 0;
}

uint8_t rtc_enable_square_wave() {
  uint8_t control_register;
  if (rtc_read_reg(CONTROL_ADDRESS, &control_register) != 0) {
    return 1;
  }

  // Enable 1Hz square wave, and set the INTCN bit to 0 to enable square waves.
  control_register &= 0xE3;

  // Enable square wave output.
  control_register |= 0x40;

  if (i2c_start(RTC_ADDRESS) != 0) {
    return 2;
  }

  if (i2c_write(CONTROL_ADDRESS) != 0) {
    return 3;
  }

  if (i2c_write(control_register) != 0) {
    return 4;
  }

  i2c_stop();

  return 0;
}

void rtc_disable_square_wave() {
}

uint8_t rtc_inc_hours() {
  uint8_t hours;
  if (rtc_read_reg(HOURS_ADDRESS, &hours) != 0) {
    return 1;
  }

  uint8_t is_24_hour = (hours & (1 << 6)) == 0;
  if (is_24_hour) {
    uint8_t time = bcd2dec(hours);
    if (rtc_write_reg(HOURS_ADDRESS, dec2bcd((time + 1) % 24)) != 0) {
      return 2;
    }
  } else {
    uint8_t new_time = ((bcd2dec((hours & 0x1F)) + 1) % 13);
    if (new_time == 0) {
      new_time = 1;
    }
    rtc_write_reg(HOURS_ADDRESS,
                  (hours & (1 << 6)) | (hours & (1 << 5)) | dec2bcd(new_time));
  }

  return 0;
}

uint8_t rtc_inc_mins() {
  uint8_t mins;
  if (rtc_read_minutes(&mins) != 0) {
    return 1;
  }

  if (rtc_write_reg(MINUTES_ADDRESS, dec2bcd((mins + 1) % 60)) != 0) {
    return 2;
  }

  return 0;
}

uint8_t rtc_inc_secs() {
  uint8_t secs;
  if (rtc_read_seconds(&secs) != 0) {
    return 1;
  }

  if (rtc_write_reg(SECONDS_ADDRESS, dec2bcd((secs + 1) % 60)) != 0) {
    return 2;
  }

  return 0;
}

uint8_t rtc_set_secs(uint8_t s) {
  return rtc_write_reg(SECONDS_ADDRESS, dec2bcd(s));
}

uint8_t rtc_set_24hour(uint8_t is_24_hour) {
  uint8_t hours;
  if (rtc_read_reg(HOURS_ADDRESS, &hours) != 0) {
    return 1;
  }

  if (is_24_hour) {
    return rtc_write_reg(HOURS_ADDRESS, hours & ~(1 << 6));
  } else {
    return rtc_write_reg(HOURS_ADDRESS, hours | (1 << 6));
  }
}

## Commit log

2015-09-03 Initial firmware commit.
    Add firmware for the clock, which can currently set the time, display the time,
    and optionally replace the seconds display with a fahrenheit temperature
    display.
    [main.c, rtc.c]
2015-09-03 Initial commit of KiCad files for clock LED board.
    [lcdb4.dsn, lcdb4.kicad_pcb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]
2015-09-03 Initial commit of KiCad files for clock board.
    [cb2.dsn, cb2.kicad_pcb, cb2.sch]
2015-09-06 Update a TODO for moving to proper clock board.
2015-09-13 A little more documentation of the two boards' BOMs.
2015-09-13 Add an image of the bare LED board.
2015-09-18 Add images of the led board schematic and PCB.
2015-09-18 Add to the README images of LED PCB and Schematic.
2015-10-10 Removed clock reset button. Improved PCB layout.
    [_saved_cb2.sch, cb2.dsn, cb2.kicad_pcb]
2015-10-10 Updated footprints for DS3231, 4.7k resistors, and battery connection.
    [_saved_cb2.sch, cb2.kicad_pcb]
2015-11-01 Read the time one 1-second intervals as dictated by the DS3231 square wave.
    Fixed a bug in RTC I2C communications where all read bytes were being BCD
    decoded.
    Got rid of the unused LED pin.
    Enabled the 1Hz square wave on the DS3231.
    Changed the schematic to no longer use the 32KHz wave and instead connect the
    1Hz square wave to INT1, and only trigger INT1 on falling edges.
    [cb2.sch]
2015-11-01 Add the pullup resistor for the DS3231 square wave.
    [cb2.sch]
2015-11-01 Keep the last digit from pulsing on the second.
    Now that fetching the time is driven by interrupt, the time taken to fetch the
    time would leave the last digit in the cycle enabled for a fractionally longer
    amount of time. This causes the last digit to slightly visibly pulse brighter
    when fetching the time.
    Disabling the last digit right before fetching the time fixes the problem.
    [main.c]
2015-11-08 Allow setting the hours, minutes, and seconds.
    Introduce a button struct which performs button debouncing.
    Introduce rtc functions to allow incrementing hours, mins, and seconds.
2015-11-08 Change the seconds button to be a seconds hold toggle.
    Also cleanup the button pressed logic.
2015-11-08 Add is_button_lifted() to check for button up.
    Also document the button class.
2015-11-08 Forgot to change refactored button function names in c file.
2015-11-10 Clock board Rev A with routing and placement.
    [cb2.dsn, cb2.kicad_pcb, cb2.sch]
2015-11-22 Add images for the clock board PCB and schematic to the README.
2015-11-27 Switch the i2c pins to the final board layout.
2015-11-27 Implement the temperature toggle button.
2015-11-27 Add an image of the bare clock board.
2015-11-27 Update README to include bare clock board PCB.
2015-11-27 Add images of LED and Clock boards populated.
2015-12-05 Add image of clock in case.
2015-12-05 Finish clock board BOM.
